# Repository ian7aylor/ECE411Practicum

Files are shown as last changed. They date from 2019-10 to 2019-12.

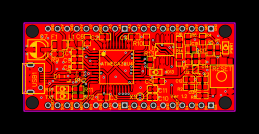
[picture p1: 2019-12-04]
PCB Design & Layout/Layout/Ver1.2/PCB_Micro-Complete-Ver1.2_20191123182726.png

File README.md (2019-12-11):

# ECE411 Practicum: Audio Spectrum Vizualizer, Team #2
## Project Overview
Our device will listen to the surounding environment through a microphone, and 
produce a visual display through an array of colorful LED lights. The LEDs are divided
into seven rows to represent the weight of seven predetermined frequencies. 
The device is powered via USB 2.0 and as a sleek design allow the the device to easily 
be portable. This makes it the perfect product for music listeners, as all they have 
to do is:
1. Power the device with a USB 2.0.
2. Play their favorite soundtrack.
3. Enjoy the visual LED display

## Useful Links
### Link: [Final Version of Board](https://github.com/ian7aylor/ECE411Practicum/tree/master/PCB%20Design%20%26%20Layout/VER1.3)
### Link: [Bill of Materials](https://github.com/ian7aylor/ECE411Practicum/blob/master/BOM/BOM.xlsx)
### Link: [Source Code](https://github.com/ian7aylor/ECE411Practicum/blob/master/Source/ECE_411_Project_Code/ECE_411_Project_Code.ino)
### Link: [Test Plan](https://github.com/ian7aylor/ECE411Practicum/blob/master/Testing/Homework%207%20-%20Test%20Plan.pdf)

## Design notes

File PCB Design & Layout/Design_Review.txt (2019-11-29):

Design Review Notes - Team #2 (Nick Long, Marcus Chalona, Ali Saad, Ian Taylor)
Reviewer: Professor Greenberg 

- Don't know what the schematic is of. Need to better label all parts of the schematic. (fixed)
- Needs to have a "useful" name (fixed)
- 10000 ft view, what does the device do? Should not be a mystery. (fixed)
Solution: Added a title that clearly describes the product. Clearly labeled all major pieces of the schematic.

- Symbols were disliked. In particular the Op-Amp symbol was not liked. (fixed)
Solution: The filter schematic was replaced by an IC. We are no longer building filters from scratch.

Different ground symbols were on the filter circuit. (fixed)
Solution: This is no longer an issue. All ground symbols are the same now.

- LM324 - Put inputs to ground if not used
- Ground VCC on LM324 (fixed)
- Put a decoupling capacitor on the op amp. (fixed)
Solution: We are no longer using the LM324 op-amp.

- Pin Headers need to be labeled. (fixed)
Solution: All pin headers are now labeled.

- Connections to LED Strips/Array (fixed)
Solution: There are now 3 pins for the 8x8 LED array. They connect to the D7 data input, ground, and +5V.

 - 1 Decoupling cap per VCC (fixed)
 Solution: All VCCs now have an assoicated decoupling cap. 
 
 - No stitching ground plane (fixed)
 Solution: Ground planes are now stitched together. There is now one reference across all layers of the board.
 
 - via to connect ground planes (fixed)
 Solution: vias have been added.

 - No reason to use 6 mil wires. (fixed)
 - The wires need to be orthogonal to the pads. (Working on)
Solution: Wire size has been increased to 10 mil, and wires are now orthogonal to pads with proper spacing.

Board has now been finalized and sent out to LCSC for manufacturing.

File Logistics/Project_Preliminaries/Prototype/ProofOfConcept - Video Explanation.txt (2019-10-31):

List of items seen in the video:
1. The 1st shot shows the ADC values being displayed on the serial monitor in the Arduino IDE.
These values are coming from the outputs of the three bandpass filters.
2. The next item seen is the bandpass filter circuit. The LEDs light up when the freuency band goes through/
The closer to the center frequency, the brighter the LED gets.
3. The potentiometers change the feedback resistance to the amplifier that goes to the speaker.
4. The oscilloscope is displaying the signal that would go to the NeoPixel matrix. This particular
signal would say "Howdy!" across the LED matrix.

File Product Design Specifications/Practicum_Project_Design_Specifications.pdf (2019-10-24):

# Practicum

## ViSound Project Design Specifications

V.1

Portland State University

Maseeh College of Engineering & Computer Science

Department of Electrical & Computer Engineering

### Authors:

Nick Long

Marcus Chalona

Ali Saad

Ian Taylor

### October 24, 2019

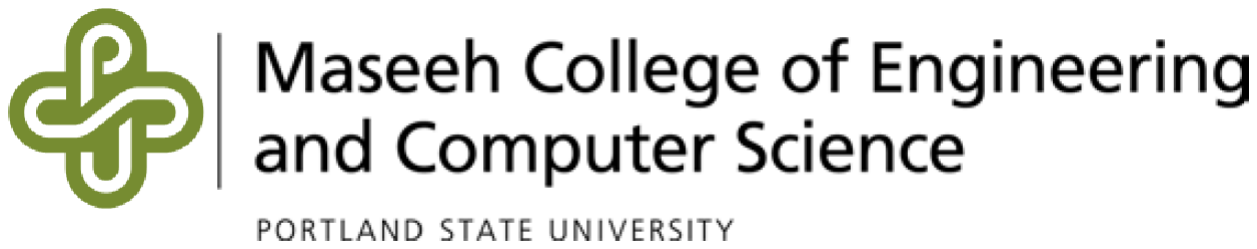
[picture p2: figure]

ECE 411

Industry Design Processes

Lab 1 Report | PSU ECE 411

## Contents

1 Project Summary | 2
2 Market Analysis | 3
3 Requirements | 4
4 System Architecture | 5
5 Design Specification | 6
1900 SW 4th Ave,, Portland, OR 97201 • https://github.com/ECE411Practicum (https://github.com/ian7aylor/ECE411Practicum/) | 1

## 1 Project Summary

ViSound is a device that when powered by a USB 2.0, will listen to the environment through a microphone, and produce a visual display through an array of colorful LED lights. The USB 2.0 feature allows for the device to be portable. This is the perfect product for music listeners, as all they have to do is:

1. Power the device with a USB 2.0.
2. Play their favorite soundtrack.
3. Enjoy the visual LED display.

This product is not only great for music, but also is an item that electronic enthusiasts can tinker with. The USB 2.0 input powers the device, and can be accessed to reprogram the microprocessor. The initial code for this device is provided at https://github.com/ian7aylor/ECE411Practicum and is commented in a user-friendly manner. In order for a user to program the LED display, they should:

1. Plug the device into their computer via USB 2.0.
2. Go to https://github.com/ian7aylor/ECE411Practicum for examples.
3. Reprogram the LED display.
4. Enjoy their unique device.
1900 SW 4th Ave,, Portland, OR 97201 • https://github.com/ECE411Practicum (https://github.com/ian7aylor/ECE411Practicum/) | 2

## 2 Market Analysis

The intended customer base for ViSound are:

- music listeners
- electronic enthusiasts

This is the targeted customer base, but this device can ultimately be used by anyone. There are a few competitors out there that have similar products to ViSound . A couple of these companies are:

- Nobsound
- Nanoleaf

Nobsound has a frequency spectrum analyzer for high fidelity. This is a handheld spectrum analyzer that does a frequency sweep and displays the power for each frequency band with LEDs. The LEDs are monochromatic. This device costs $139. Nanoleaf light panels are smart lights, meaning they can connect to the user’s WiFi. They sell an attachment called a rhythm module that can be attached to their light panels. The user can program the rhythm and color scheme of the LED panels through the Nanoleaf mobile app. When there are environmental sounds, the lights will dance. The minimum cost for this setup is $200.
Companies like Nanoleaf and Nobsound are competitors because their products create an LED visual display in response to environmental sounds. The main difference between ViSound and its competitors, is that the LED visualizations provide information about which frequency band is being displayed, and the user can program the device to create different visual representations for each frequency band. ViSound is also priced at $69.99 which covers the cost of materials, labor, and approximately $40 to put back into the business. This puts this device at close to half the price of our competitors.
1900 SW 4th Ave,, Portland, OR 97201 • https://github.com/ECE411Practicum (https://github.com/ian7aylor/ECE411Practicum/) | 3

## 3 Requirements

Must

- Have a microphone as a sensor (input).
- Have an amplifier stage to boost the input signal.
- Have Neopixel LEDs as actuators (outputs).
- Have a two layer PCB.
- Have 25% or more surface mount components that can be hand or reflow soldered.
- Have a digital or analog processor.
- Be safe
- Have bandpass filters to isolate each frequency band.
- Use USB 2.0 for power and programming.
- Have comments that describe the code in detail.

Should

- Be portable.
- Have a translucent case.
- Be easy to setup.
- Have a wide range of colors.

May

- Be easy for an inexperienced individual to reprogram.
- Be expandable to add or remove pixels.
1900 SW 4th Ave,, Portland, OR 97201 • https://github.com/ECE411Practicum (https://github.com/ian7aylor/ECE411Practicum/) | 4

## 4 System Architecture

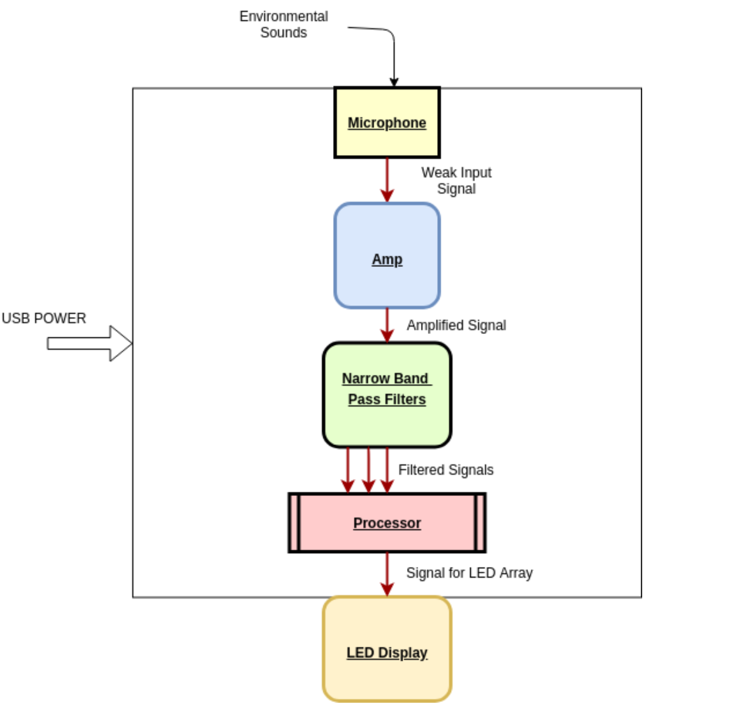
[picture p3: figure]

Figure 1: ViSound - System Architecture

1900 SW 4th Ave,, Portland, OR 97201 • https://github.com/ECE411Practicum (https://github.com/ian7aylor/ECE411Practicum/) | 5

## 5 Design Specification

What is the sensor?

- Microphone (INGHAi GMI6050P-46db)

What is the processor?

- ATMEGA32U4-AU

What is the actuator?

- WS2812 5050 RGB LED with Integrated Drivers

What provides the power?

- USB 2.0 - 5V source(removable male micro-B to male standard type A cable)

What is the mechanical design?

- Translucent Polycarbonate Project Box

What is the firmware?

- Bootloader

What is the programming language?

- AVR C++

Is an Arduino being used? (Y/N)

- Yes

What is the development environment?

- Arduino IDE
1900 SW 4th Ave,, Portland, OR 97201 • https://github.com/ECE411Practicum (https://github.com/ian7aylor/ECE411Practicum/) | 6

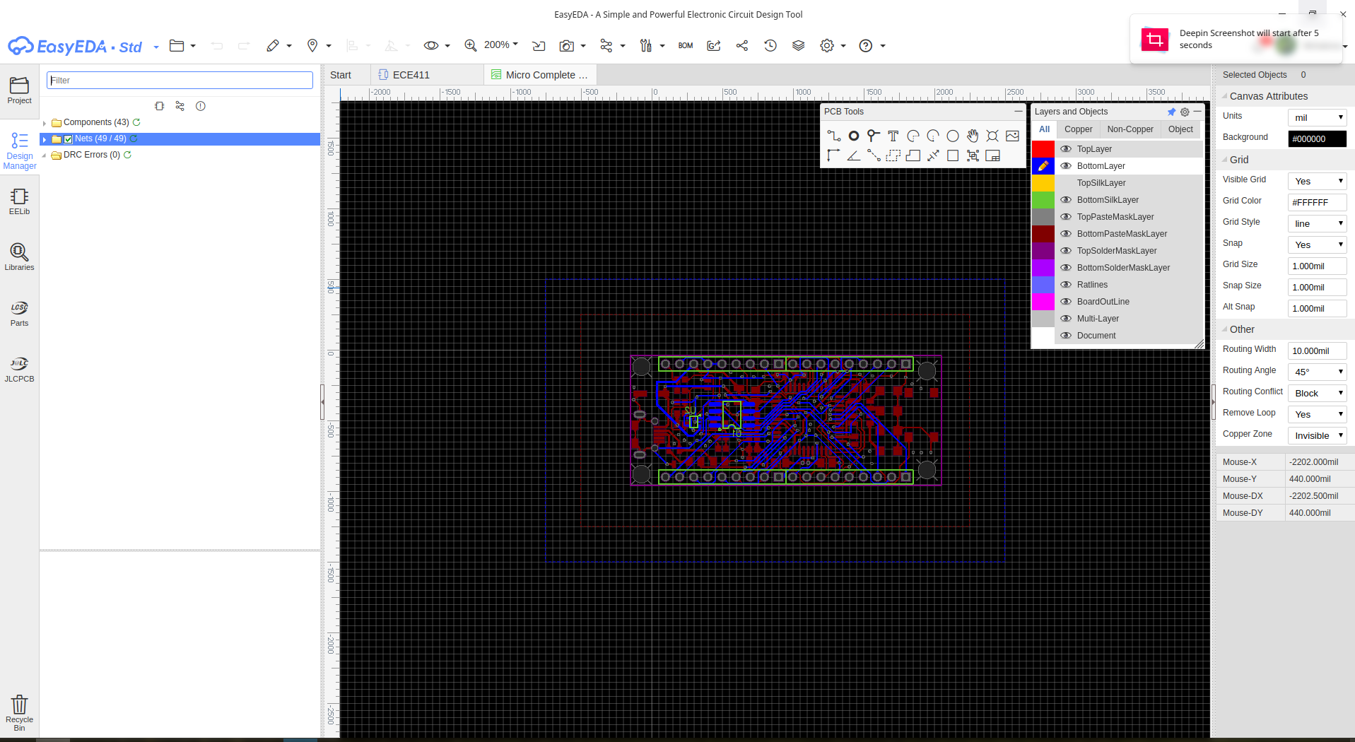
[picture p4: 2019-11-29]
PCB Design & Layout/rulecheck for Ver1.1.png

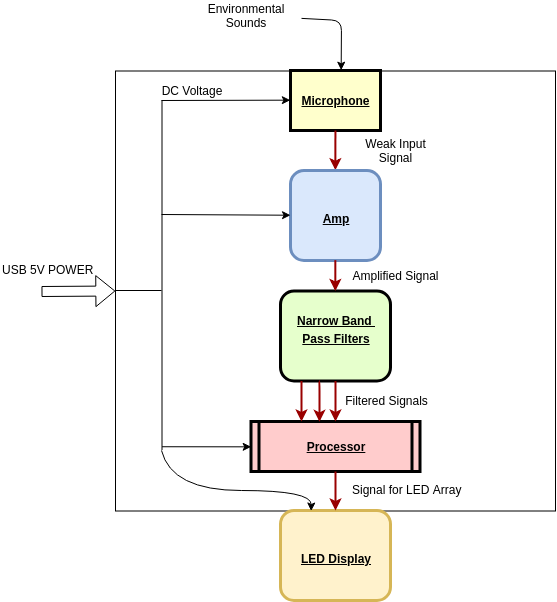
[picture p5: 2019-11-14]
Product Design Specifications/block Diagram.png

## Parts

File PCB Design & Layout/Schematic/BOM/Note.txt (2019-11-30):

BOM needs to be update so that we can use this for board assembly on Monday

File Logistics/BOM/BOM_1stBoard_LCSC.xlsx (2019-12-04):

LCSC Part Number | Manufacture Part Number | Manufacturer | Customer NO. | Package | Description | RoHS | Order Qty. | Min\Mult Order Qty. | Unit Price | Order Price
C10418 | C10418 | Jing Extension of the Electronic Co. |  | SMD | USB Connectors SMD RoHS | Yes | 35 | 5\5 | $0.0576 | $2.02
C106264 | SMD1206P050TF/15 | Polytronics Tech |  | 1206 | PTC Resettable Fuses 1206 RoHS | Yes | 45 | 5\5 | $0.0853 | $3.84
C118556 | 9018H | Semtech |  | TO-92(TO-92-3) | Transistors (NPN/PNP) NPN 50mA 15V TO-92(TO-92-3) RoHS | Yes | 200 | 20\20 | $0.0118 | $2.36
C126020 | LM1117F-5.0 | HTC Korea TAEJIN Tech |  | SOT-89(SOT-89-3) | Low Dropout Regulators(LDO) Positive Fixed 1.3V @ 1A 12V 5V 1A SOT-89(SOT-89-3) RoHS | Yes | 45 | 1\1 | $0.0879 | $3.96
C149873 | CRA064RJ1K00E04Z | Ever Ohms Tech |  | 1206_x4 | Resistor Networks & Arrays 1KOhms ±5% 1/4W 1206_x4 RoHS | Yes | 45 | 5\5 | $0.065 | $2.93
C17513 | 0805W8F1001T5E | Uniroyal Elec |  | 0805 | Chip Resistor - Surface Mount 1KOhms ±1% 1/8W 0805 RoHS | Yes | 700 | 100\100 | $0.0016 | $1.12
C2174 | X206016MSD2SC | Yangxing Tech |  | Radial,2x6mm | Radial Cylinder Crystals 16MHz ±20ppm Radial,2x6mm RoHS | Yes | 20 | 5\5 | $0.0648 | $1.3
C23289 | RVT1V220M0505 | Honor Elec |  | SMD,5x5.4mm | Aluminum Electrolytic Capacitors - SMD 22uF ±20% 35V SMD,5x5.4mm RoHS | Yes | 80 | 20\20 | $0.026 | $2.08
C24658 | 0805CG220J500NT | Guangdong Fenghua Advanced Tech |  | 0805 | Multilayer Ceramic Capacitors MLCC - SMD/SMT 22pF 50V 0805 RoHS | Yes | 300 | 50\50 | $0.0052 | $1.56
C25295 | 0805W8J0220T5E | Uniroyal Elec |  | 0805 | Chip Resistor - Surface Mount 22Ohms ±5% 1/8W 0805 RoHS | Yes | 1200 | 100\100 | $0.0009 | $1.08
C26413 | CL10A105KP8NNNC | Samsung Electro-Mechanics |  | 0603 | Multilayer Ceramic Capacitors MLCC - SMD/SMT 1uF 10V 0603 RoHS | Yes | 100 | 20\20 | $0.0211 | $2.11
C284938 | LTST-C21KGKT | Lite-On |  | SMD,3.2x1.6x1.1mm | Light Emitting Diodes (LED) Green 567.5~576.5nm 28~180mcd Surface Mount SMD,3.2x1.6x1.1mm RoHS | Yes | 45 | 5\5 | $0.0634 | $2.86
C284940 | LTST-C21KSKT | Lite-On |  | SMD,3.2x1.6x1.1mm | Light Emitting Diodes (LED) Yellow 587nm 28~450mcd Surface Mount SMD,3.2x1.6x1.1mm RoHS | Yes | 60 | 5\5 | $0.0468 | $2.81
C284941 | LTST-C21TBKT | Lite-On |  | SMD,3.2x1.6x1.1mm | Light Emitting Diodes (LED) Blue 465~475nm 45~280mcd Surface Mount SMD,3.2x1.6x1.1mm RoHS | Yes | 45 | 5\5 | $0.0634 | $2.86
C294565 | TSA063G50-250 | BRIGHT |  | SMD | Tactile Switches SPST 6.10mm x 6.10mm 1.50mm 50mA @ 12VDC SMD RoHS | Yes | 60 | 20\20 | $0.0207 | $1.25
C305407 | 9012-H | Foshan Blue Rocket Elec |  | TO-92 | Transistors (NPN/PNP) PNP 500mA 20V TO-92 RoHS | Yes | 200 | 20\20 | $0.0121 | $2.42
C356820 | AZ5125-02S.R7G | AMAZING |  | SOT23-3L | TVS SOT23-3L RoHS | Yes | 70 | 10\10 | $0.0347 | $2.43
C50503 | MLB2012-300P3A(f) | Meled Industrial |  | 0805 | Beads 0805 RoHS | Yes | 150 | 50\50 | $0.0087 | $1.31
C50981 | C50981 | Boom Precision Elec |  | 2.54mm | Pin Header & Female Header 2.54mm RoHS | Yes | 70 | 5\5 | $0.0453 | $3.18
C75469 | FDN340P | ON Semicon |  | SOT-23(SOT-23-3) | MOSFET P Trench 20V 2A 1.5V @ 250uA 70 mΩ @ 2A,4.5V SOT-23(SOT-23-3) RoHS | Yes | 70 | 1\1 | $0.0818 | $5.73
C84376 | RC0805FR-0710KL | YAGEO |  | 0805 | Chip Resistor - Surface Mount 10KOhms ±1% 1/8W 0805 RoHS | Yes | 300 | 100\100 | $0.0017 | $0.51
C88136 | 0603B104J500NT | Guangdong Fenghua Advanced Tech |  | 0603 | Multilayer Ceramic Capacitors MLCC - SMD/SMT 100nF 50V 0603 RoHS | Yes | 200 | 50\50 | $0.0091 | $1.82
C95414 | LP2985-33DBVR | Texas Instruments |  | SOT-23-5 | Low Dropout Regulators(LDO) Positive Fixed 575mV @ 150mA 16V 3.3V 150mA SOT-23-5 RoHS | Yes | 50 | 1\1 | $0.2273 | $11.37
Manufacturer Part Number | Manufacturer | Digi-Key Part Number | Customer Reference | Reference Designator | Packaging | Part Status | Quantity | Unit Price | Extended Price | Quantity Available | Mfg Std Lead Time | Description | RoHS Status | Lead Free Status | REACH Status
CMEJ-4618-42-L015 | CUI Devices | 102-6532-ND |  |  | Box | Active | 1 | 0.52 | $0.52 | 3442 | 6 Weeks | MICROPHONE, 4.6 MM, ELECTRET CON | RoHS Compliant | Lead free | Not Available
ATMEGA32U4-AUR | Microchip Technology | ATMEGA32U4-AURCT-ND |  |  | Cut Tape (CT) | Active | 1 | 4.08 | $4.08 | 0 | 6 Weeks | IC MCU 8BIT 32KB FLASH 44TQFP | ROHS3 Compliant | Lead free | REACH Unaffected

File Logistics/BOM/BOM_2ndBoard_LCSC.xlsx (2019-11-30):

LCSC Part Number | Manufacture Part Number | Manufacturer | Package | Customer # | Description | RoHS | Order Qty. | Min\Mult Order Qty. | Unit Price | Order Price | Product Link
C25811 | 0603WAF2003T5E | UNI-ROYAL(Uniroyal Elec) | 603 |  | 200K ±1% 1/10W 0603 Chip Resistor - Surface Mount RoHS | - | 1200 | 100\100 | 0.0006 | 0.72 | https://lcsc.com/product-detail/Chip-Resistor-Surface-Mount_UNI-ROYAL-Uniroyal-Elec-0603WAF2003T5E_C25811.html
C14675 | RC0603FR-07100KL | YAGEO | 603 |  | 100K ±1% 1/10W 0603 Chip Resistor - Surface Mount RoHS | - | 1000 | 100\100 | 0.0007 | 0.7 | https://lcsc.com/product-detail/Chip-Resistor-Surface-Mount_YAGEO-RC0603FR-07100KL_C14675.html
C309445 | AF122-JR-0722RL | YAGEO | 0402x2 |  | 22 ±5% 1/16W 0402x2 Resistor Networks & Arrays RoHS | - | 100 | 50\50 | 0.0145 | 1.45 | https://lcsc.com/product-detail/Resistor-Networks-Arrays_YAGEO-AF122-JR-0722RL_C309445.html
C88136 | 0603B104J500NT | FH(Guangdong Fenghua Advanced Tech) | 603 |  | 100nF 50V 0603 Multilayer Ceramic Capacitors MLCC - SMD/SMT RoHS | - | 100 | 50\50 | 0.0095 | 0.95 | https://lcsc.com/product-detail/Multilayer-Ceramic-Capacitors-MLCC-SMD-SMT_FH-Guangdong-Fenghua-Advanced-Tech-0603B104J500NT_C88136.html
C1635 | 0603CG101J500NT | FH(Guangdong Fenghua Advanced Tech) | 603 |  | 100pF 50V 0603 Multilayer Ceramic Capacitors MLCC - SMD/SMT RoHS | - | 400 | 100\100 | 0.0028 | 1.12 | https://lcsc.com/product-detail/Multilayer-Ceramic-Capacitors-MLCC-SMD-SMT_FH-Guangdong-Fenghua-Advanced-Tech-0603CG101J500NT_C1635.html
C305012 | RTT031002BTP | RALEC | 603 |  | 10K ±0.1% 1/10W 0603 Chip Resistor - Surface Mount RoHS | - | 60 | 20\20 | 0.0227 | 1.362 | https://lcsc.com/product-detail/Chip-Resistor-Surface-Mount_RALEC-RTT031002BTP_C305012.html
C124567 | 0603B103J500NT | FH(Guangdong Fenghua Advanced Tech) | 603 |  | 10nF 50V 0603 Multilayer Ceramic Capacitors MLCC - SMD/SMT RoHS | - | 200 | 50\50 | 0.0053 | 1.06 | https://lcsc.com/product-detail/Multilayer-Ceramic-Capacitors-MLCC-SMD-SMT_FH-Guangdong-Fenghua-Advanced-Tech-0603B103J500NT_C124567.html
C115325 | RS-03K1001FT | FH(Guangdong Fenghua Advanced Tech) | 603 |  | 1K ±1% 1/10W 0603 Chip Resistor - Surface Mount RoHS | - | 1600 | 100\100 | 0.0006 | 0.96 | https://lcsc.com/product-detail/Chip-Resistor-Surface-Mount_FH-Guangdong-Fenghua-Advanced-Tech-RS-03K1001FT_C115325.html
C388038 | 0603N220F500CT | Walsin Tech Corp | 603 |  | 22pF 50V 0603 Multilayer Ceramic Capacitors MLCC - SMD/SMT RoHS | - | 100 | 50\50 | 0.0088 | 0.88 | https://lcsc.com/product-detail/Multilayer-Ceramic-Capacitors-MLCC-SMD-SMT_Walsin-Tech-Corp-0603N220F500CT_C388038.html
C105578 | RC0603FR-071ML | YAGEO | 603 |  | 1M ±1% 1/10W 0603 Chip Resistor - Surface Mount RoHS | - | 1600 | 100\100 | 0.0007 | 1.12 | https://lcsc.com/product-detail/Chip-Resistor-Surface-Mount_YAGEO-RC0603FR-071ML_C105578.html
C105576 | RC0603FR-072KL | YAGEO | 603 |  | 2K ±1% 1/10W 0603 Chip Resistor - Surface Mount RoHS | - | 1600 | 100\100 | 0.0007 | 1.12 | https://lcsc.com/product-detail/Chip-Resistor-Surface-Mount_YAGEO-RC0603FR-072KL_C105576.html
C296062 | 0603N330F500CT | Walsin Tech Corp | 603 |  | 33pF 50V 0603 Multilayer Ceramic Capacitors MLCC - SMD/SMT RoHS | - | 200 | 50\50 | 0.0117 | 2.34 | https://lcsc.com/product-detail/Multilayer-Ceramic-Capacitors-MLCC-SMD-SMT_Walsin-Tech-Corp-0603N330F500CT_C296062.html

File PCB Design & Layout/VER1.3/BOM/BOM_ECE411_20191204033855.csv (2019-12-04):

ID | Name | Designator | Footprint | Quantity | Manufacturer Part | Manufacturer | Supplier | Supplier Part | LCSC Assembly
1 | AZ5125-02S.R7G | D1 | SOT-23-3_L2.9-W1.6-P1.90-LS2.8-BR | 1 | AZ5125-02S.R7G | AMAZING | LCSC | C356820
2 | 100K | R3 | 0603' | 1 | RC0603FR-07100KL | YAGEO | LCSC | C14675
3 | ATMEGA32U4-AU | ATMEGA32U4 | QFP-44_10X10X08P | 1 | ATMEGA32U4-AU | MICROCHIP | LCSC | C44854 | Yes
4 | LTST-C21TBKT | PWR1 | LED-SMD-3.2X1.6X1.1 | 1 | LTST-C21TBKT | Lite-On | LCSC | C284941
5 | 22 | RN2 | RES-ARRAY-SMD_0402-4P-L1.0-W1.0-BL | 1 | AF122-JR-0722RL | YAGEO | LCSC | C309445
6 | LTST-C21KGKT | IO13 | LED-SMD-3.2X1.6X1.1 | 1 | LTST-C21KGKT | Lite-On | LCSC | C284938
7 | LTST-C21KSKT | RX1,TX1 | LED-SMD-3.2X1.6X1.1 | 2 | LTST-C21KSKT | Lite-On | LCSC | C284940
8 | A2541WV-9P | H2,H3,H1,H4 | SIP-2.54MM-9P-CJT-H8.54 | 4 | A2541WV-9P | Changjiang Connectors | LCSC | C225484
9 | 30Ω | L1 | 0805' | 1 | MLB2012-300P3A(f) | ReliaPro | LCSC | C50503
10 | 100nF | C2,C14,C3,C4,C8,C1,C5 | 0603' | 7 | 0603B104J500NT | FH | LCSC | C88136
11 | 100pF | C13 | 0603' | 1 | 0603CG101J500NT | FH | LCSC | C1635 | Yes
12 | 10K | R2,R8,R9 | 0603' | 3 | RTT031002BTP | RALEC | LCSC | C305012
13 | micro USBFemale | USB1 | MICRO-USB-1 | 1 | micro USBFemale | ValuePro | LCSC | C10418
14 | MAX4466EXK+T | U2 | SC-70-5 | 1 | MAX4073TAXK+T | Maxim Integrated | LCSC | C143459 | Yes
15 | 10nF | C15,C17 | 0603' | 2 | 0603B103J500NT | FH | LCSC | C124567
16 | 16MHz | X1 | TXAL-1.9*6 | 1 | X206016MSD2SC | YXC | LCSC | C2174
17 | 1uF | C9,C12,C6 | 0603' | 3 | CL10A105KP8NNNC | SAMSUNG | LCSC | C26413
18 | 1K | R1,R13,R12,R11,R10 | 0603' | 5 | RS-03K1001FT | FH | LCSC | C115325
19 | TSA063G50-250 | RESET | SW-SMD-T6X6-9.5X5.8 | 1 | TSA063G50-250 | BRIGHT | LCSC | C294565
20 | MSGEQ7SOIC | U1 | SOIC-8 | 1
21 | 22uF | C7 | CAP-SMD_BD5.0-L5.3-W5.3-FD | 1 | RVT1V220M0505 | HONOR | LCSC | C23289
22 | 200K | R14 | R0603 | 1 | CR0603F200KP05 | Ever Ohms Tech | LCSC | C429255
23 | 22pF | C10,C11 | CAP_0603 | 2 | 0603N220F500CT | Walsin Tech Corp | LCSC | C388038
24 | 1M | R6,R7 | 0603' | 2 | RC0603FR-071ML | YAGEO | LCSC | C105578
25 | 2K | R4,R5 | 0603' | 2 | RC0603FR-072KL | YAGEO | LCSC | C105576
26 | SMD1206P050TF/15 | F1 | FUSE-1206 | 1 | SMD1206P050TF/15 | PTTC | LCSC | C106264
27 | 33pF | C16 | 0603' | 1 | 0603N330F500CT | Walsin Tech Corp | LCSC | C296062

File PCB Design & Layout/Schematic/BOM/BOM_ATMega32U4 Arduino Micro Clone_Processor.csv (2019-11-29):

ID | Name | Designator | Footprint | Quantity | Manufacturer Part | Manufacturer | Supplier | Supplier Part | LCSC Assembly
1 | none | A |  | 1
2 | AZ5125-02S.R7G | D1 | SOT-23-3_L2.9-W1.6-P1.90-LS2.8-BR | 1 | AZ5125-02S.R7G | AMAZING | LCSC | C356820
3 | ATMEGA32U4-AU | ATMEGA1U4-AU | QFP-44_10X10X08P | 1 | ATMEGA32U4-AU | MICROCHIP | LCSC | C44854 | Yes
4 | LTST-C21TBKT | PWR1 | LED-SMD-3.2X1.6X1.1 | 1 | LTST-C21TBKT | Lite-On | LCSC | C284941
5 | LTST-C21KGKT | IO1 | LED-SMD-3.2X1.6X1.1 | 1 | LTST-C21KGKT | Lite-On | LCSC | C284938
6 | 1K | RN1 | 1206_X4 | 1 | CRA064RJ1KE04 | EVER OHMS | LCSC | C149873
7 | 1K | R2 | 0805' | 1 | 0805W8F1001T5E | UniOhm | LCSC | C17513 | Yes
8 | LTST-C21KSKT | TX1,RX1 | LED-SMD-3.2X1.6X1.1 | 2 | LTST-C21KSKT | Lite-On | LCSC | C284940
9 | A2541WV-9P | H3,H1,H2,H4 | SIP-2.54MM-9P-CJT-H8.54 | 4 | A2541WV-9P | Changjiang Connectors | LCSC | C225484
10 | 22pF | C11,C10 | 0805' | 2 | 0805CG220J500NT | FH | LCSC | C24658
11 | 30Ω | L1 | 0805' | 1 | MLB2012-300P3A(f) | ReliaPro | LCSC | C50503
12 | LP2985-33DBVR | U2 | SOT-23-5 | 1 | LP2985-33DBVR | TI | LCSC | C95414 | Yes
13 | 100nF | C4,C1,C5,C8 | 0603' | 4 | 0603B104J500NT | FH | LCSC | C88136
14 | micro USBFemale | USB1 | MICRO-USB-1 | 1 | micro USBFemale | ValuePro | LCSC | C10418
15 | 16MHz | X1 | TXAL-1.9*6 | 1 | X206016MSD2SC | YXC | LCSC | C2174
16 | FDN340P | Q2,Q1 | SOT-23-3_L2.9-W1.6-P1.90-LS2.8-BR | 2 | FDN340P | FAIRCHILD | LCSC | C75469 | Yes
17 | 1uF | C3,C9,C6 | 0603' | 3 | CL10A105KP8NNNC | SAMSUNG | LCSC | C26413
18 | TSA063G50-250 | RESET | SW-SMD-T6X6-9.5X5.8 | 1 | TSA063G50-250 | BRIGHT | LCSC | C294565
19 | 22 | R4,R3 | 0805' | 2 | 0805W8J0220T5E | UniOhm | LCSC | C25295
20 | 22uF | C7,C2 | CAP-SMD_BD5.0-L5.3-W5.3-FD | 2 | RVT1V220M0505 | HONOR | LCSC | C23289
21 | LM1117F-5.0 | U1 | SOT-89(SOT-89-3) | 1 | LM1117F-5.0 | HTC | LCSC | C126020 | Yes
22 | 10K | R1,R5 | 0805' | 2 | RC0805FR-0710KL | YAGEO | LCSC | C84376
23 | SMD1206P050TF/15 | F1 | FUSE-1206 | 1 | SMD1206P050TF/15 | PTTC | LCSC | C106264

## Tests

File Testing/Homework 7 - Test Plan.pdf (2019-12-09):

Homework 7 - Audio Spectrum Visualizer: System Test Plan Authors: Nicholas Long, Marcus Chalona, Ian Taylor, Ali Saad EC411- Team #2
12/3/2019 - Revision 1.0

Table of Contents

1. Introduction | 2
2. Reference Documents | 3
3. Test Objectives | 4
4. System Tests | 5
4.1 Unit Tests
4.1.1 Microphone
4.1.2 Preamplifier
4.1.3 7 Band Bandpass Filter 4.1.4 Atmel ATmega32U4
a. Matrix Array Signal
4.1.5 LED Matrix Array
4.2 Integration Tests
4.2.1 1st Stage (Microphone + Preamp)
4.2.2 2nd Stage (Atmel ATmega32U4 + 7 Band Bandpass Filter)
4.2.3 3rd Stage (Atmel ATmega32U4 + LED Matrix)
a. Signal to LED Matrix
4.2.4 1st + 2nd Stage (Atmel ATmega32U4 + 7 Band Bandpass Filter + Preamp) 4.3 Acceptance Tests
4.3.1 Frequency Sweep Mapping to LED Matrix
5. Resources
5.1 Tektronix MSO 4054 Mixed Signal Oscilloscope 5.2 Arbitrary Waveform Generator
5.3 Computer
5.3.1 Software: Atmel Studio, Arduino IDE. 5.3.2 Programing Language: Processing 5.4 Testing Cables/Probes
5.4.1 Female - Male BNC Cable
5.4.2 Oscilloscope Probes
5.5 8 Ohm Speaker
5.6 Personnel
5.6.1 Education: Electrical/Computer Engineering Student/Graduate
5.6.2 Skills required: Ability to navigate equipment such as an oscilloscope, arbitrary waveform generator, DC power supply and have C programming knowledge.

Introduction

The Audio Spectrum Visualizer is a device that takes in audio input and displays the frequency bands with their related signal strength on an LED matrix. Each frequency band is associated with a certain color. Below is a block diagram that illustrates the Audio Spectrum Visualizer on an abstract level.

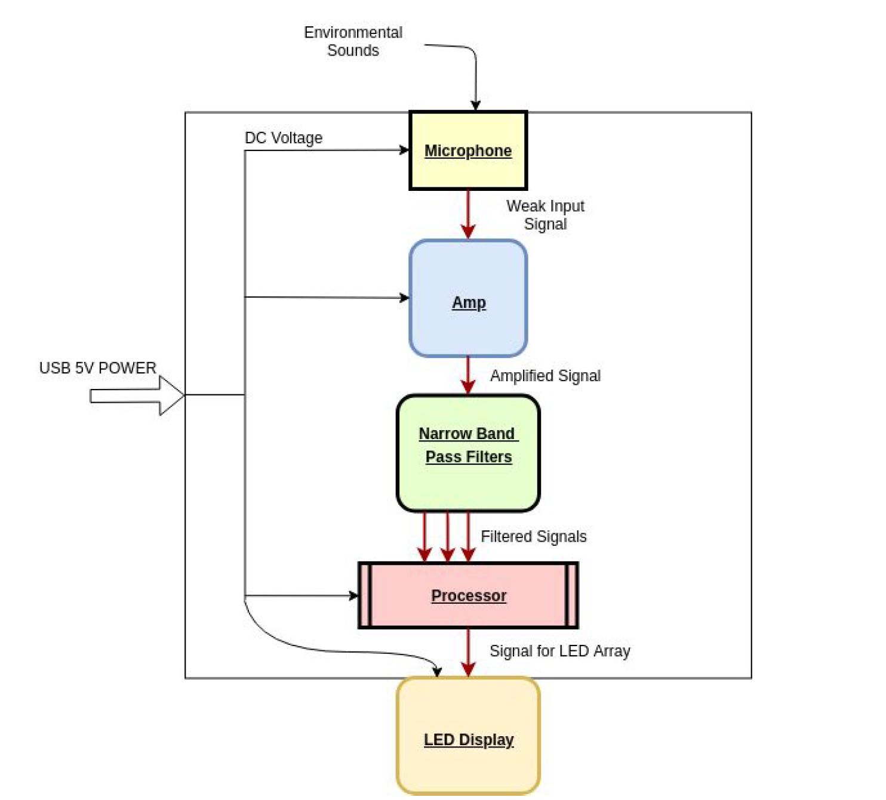
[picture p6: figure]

Reference Documentation

Below are links to all of the documents needed to thoroughly test the Audio Spectrum Visualizer.

Product Design Specifications (PDS)
Product Design Specifications (https://github.com/ian7aylor/ECE411Practicum/blob/master/Product_Design_Specifications/Practicum_Project_Design_Specifications.pdf)

Board Schematic & Layout
Ver1.3 Schematic (https://github.com/ian7aylor/ECE411Practicum/blob/master/PCB%20Design%20%26%20Layout/VER1.3/Schematic/Schematic_ECE411_ATMEGA32U4%20Micro%20Ver1.3_20191204033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)
Ver1.3 Layout (https://github.com/ian7aylor/ECE411Practicum/blob/master/PCB%20Design%20%26%20Layout/VER1.3/PCB%20Layout/PCB_Micro%20Complete%20Ver1.3_20191204033932.pdf)

Datasheets
Microphone Preamplifier (https://github.com/ian7aylor/ECE411Practicum/blob/master/Datasheets/MAX4465-MAX4469.pdf)
MSGEQ7 - Seven Band Graphic Equalizer (https://github.com/ian7aylor/ECE411Practicum/blob/master/Datasheets/MSGEQ7.pdf) SK6812 - Programmable LED (https://github.com/ian7aylor/ECE411Practicum/blob/master/Datasheets/SK6812%2BLED%2Bdatasheet%2B.pdf)
Atmel ATmega32U4 - 8-bit microcontroller (https://github.com/ian7aylor/ECE411Practicum/blob/master/Datasheets/atmel-7766-8-bit-avr-atmega16u4-32u4_datasheet.pdf) WS2812B - Intelligent Control LED (https://github.com/ian7aylor/ECE411Practicum/blob/master/Datasheets/WS2812B.pdf)

Test Objectives

Unit Testing:
Testing each individual module using the module’s specification as a description of desired behavior helps to ensure that each individual system is working correctly prior to integration. The systems that need to work according to their datasheet prior to integration are:
- MSGEQ7 7 band bandpass filter
- Microphone
- Microphone Preamplifier
- Atmel Atmega32U4 8-bit microcontroller
Once these units have been thoroughly tested and meet the specifications of their respective datasheets, we can confidently move onto integration testing.

Integration Testing:
The purpose of integration testing is to ensure that the modules interact correctly when connected to one another. Each interface needs to be exercised prior to the entire system being put together. Once integration testing has been thoroughly completed, we can confidently assemble the Audio Spectrum Visualizer and move into acceptance testing.

Acceptance Testing:
The purpose for acceptance testing in our project is to make sure our product design specifications (PDS) are met. This involves both functional and performance testing. Once these tests pass, the project is finalized.

System Tests

Acceptance Test Example:
Test Writers: Nicholas Long, Marcus Chalona, Ian Taylor, Ali Saad
Test Case Name: | Frequency to LED Mapping | Test ID #: | ACC-01
Description: | Verify each frequency is displayed on the correct row of an 8x8 LED matrix with their associated color. | Type: | Black Box Testing

Tester Information

| Name of Tester: | Computer Engineering / Electrical Engineering Student/ Graduate | Date:
Hardware Version: | | 1.3 | Time:
Equipment Needed: | | Audio Spectrum Visualizer (device being tested), Arbitrary Waveform Generator, BNC Speaker
Setup: | | Power on the Audio Spectrum Visualizer. Make sure the system is reset and all LEDs have no input. Set the arbitrary waveform generator to a frequency sweep from 50 Hz - 16 kHz. Using a BNC Female - Male cable, connect the arbitrary waveform generator to a speaker. Make sure the volume is up on the speaker and within 1 foot of the Audio Spectrum Visualizer. Start the frequency sweep on the waveform generator.

Step: | Action: Audio Input Frequency | Expected Result | Pass | Fail | N/A | Comments
1 | Minimum 63 Hz -Maximum 159 Hz | Column 1: LED should light up red with related power level.
2 | Minimum 160 Hz -Maximum 399 Hz | Column 2: LED should light up green with related power level.
3 | Minimum 400 Hz -Maximum 999 Hz | Column 3: LED should light up blue with related power level.
4 | Minimum 1.0 kHz -Maximum 2.4 kHz | Column 4: LED should light up yellow with related power level.
5 | Minimum 2.5 kHz -Maximum 6.2 kHz | Column 5: LED should light up purple with related power level.
6 | Minimum 6.25 kHz -Maximum 15.9 kHz | Column 6: LED should light up white with related power level.

7 | 16.0 kHz | Column 7: LED should light up Aqua with related power level.

Overall Test Result:

Unit Test Example:
Test Writers: Nicholas Long, Marcus Chalona, Ian Taylor, Ali Saad
Test Case Name: | Matrix Array Signal | Test ID #: | ATM-01
Description: | Custom communication protocol for WS2812b LED Array is in the correct frequency range to control LEDs. Frequency must be greater than 400 Hz as per the WS2812B data sheet. This is a white box test as we know the program that is uploaded on the microprocessor. | Type: | White Box Testing

Tester Information

| Name of Tester: | Level I Technician, Electrical Engineering Senior Student/Graduate | Date:
Hardware Version: | | 1.3 | Time:
Equipment Needed: | | Atmel ATmega32U4, Oscilloscope, BNC Female - Male Cable, Computer w/ Arduino software installed, Micro USB cable
Setup: | | Attach USB Power and wait 5 seconds for bootloader to initialize. Hook up BNC Female - Male cable from the oscilloscope to the output pin PE6 of the ATmega32U4. This pin can be seen on the Ver1.3 Schematic.
Step: | Action | Expected Output | Pass | Fail | N/A | Comments
1 | Upload Neopixel LED Matrix “HOWDY” example program from the Adafruit Neopixel library | Frequencies read on oscilloscope are greater than 400 Hz and less than 800 Hz.

Overall Test Result:

Integration Test:
Test Writers: Nicholas Long, Marcus Chalona, Ian Taylor, Ali Saad
Test Case Name: | Signal to LED Matrix | Test ID #: | STG3-01
Description: | LED Matrix Array responds to the signal that was developed in the unit test ATM-01 above. | Type: | White Box Testing

Tester Information

| Name of Tester: | Level I Technician, Electrical Engineering Senior Student/Graduate | Date:
Hardware Version: | | 1.3 | Time:
Equipment Needed: | | Atmel ATmega32U4, 8x8 LED Neopixel Matrix Array, Computer with Arduino software installed, Micro USB cable
Setup: | | Attach USB Power and wait 5 seconds for bootloader to initialize. Make sure the LED Matrix Array is attached to pin PE6 of the ATmega32U4. This pin can be seen on the Ver1.3 Schematic.
Step: | Action | Expected Output | Pass | Fail | N/A | Comments
1 | Upload Neopixel LED Matrix “HOWDY” example program from the Adafruit Neopixel library | “HOWDY” displays on 8x8 LED Neopixel Matrix Array

Overall Test Result:

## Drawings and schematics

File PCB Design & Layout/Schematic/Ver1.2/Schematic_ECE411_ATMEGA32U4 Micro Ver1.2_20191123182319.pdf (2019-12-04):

## Micro USB

## Analog Reference

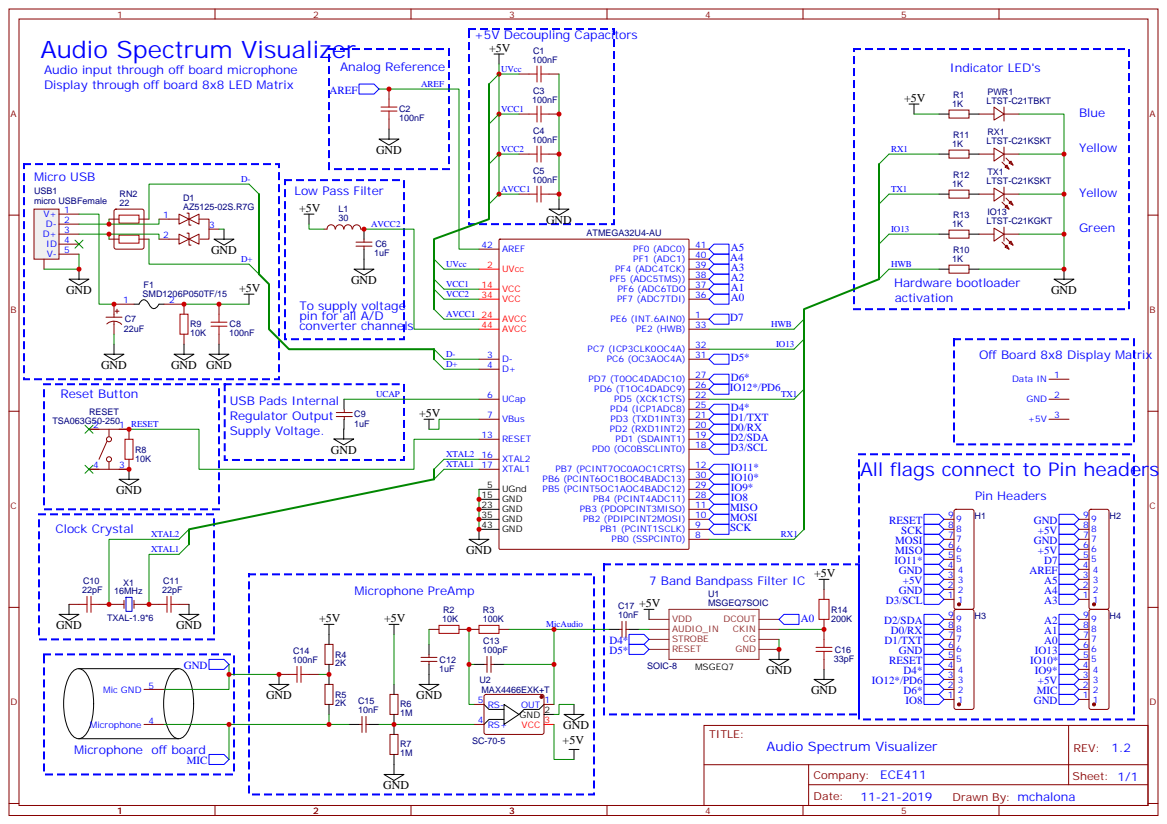
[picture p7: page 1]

Audio input through off board microphone
Display through off board 8x8 LED Matrix

Off Board 8x8 Display Matrix

All flags connect to Pin headers

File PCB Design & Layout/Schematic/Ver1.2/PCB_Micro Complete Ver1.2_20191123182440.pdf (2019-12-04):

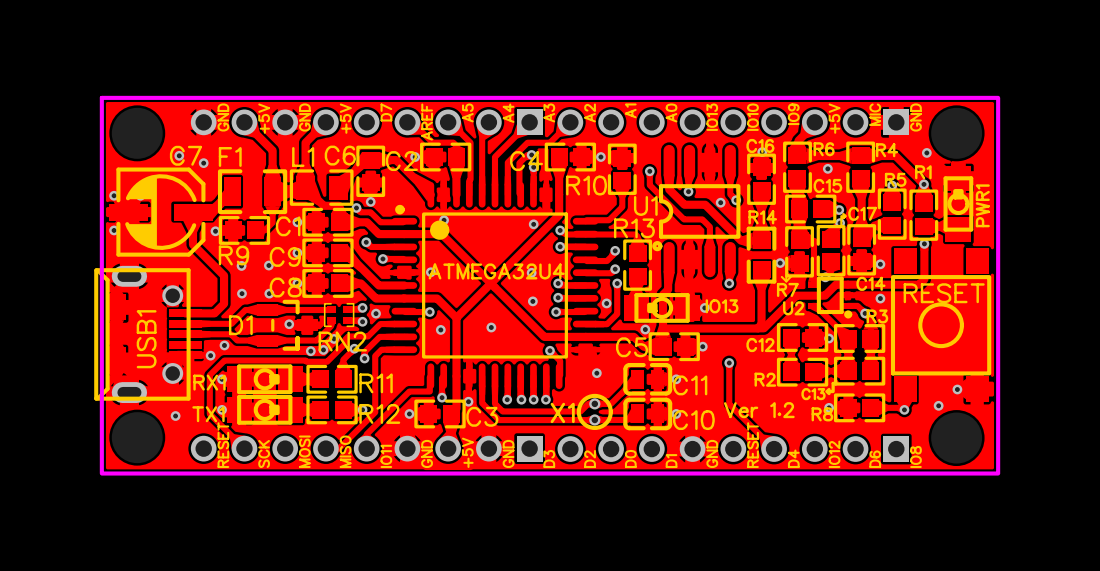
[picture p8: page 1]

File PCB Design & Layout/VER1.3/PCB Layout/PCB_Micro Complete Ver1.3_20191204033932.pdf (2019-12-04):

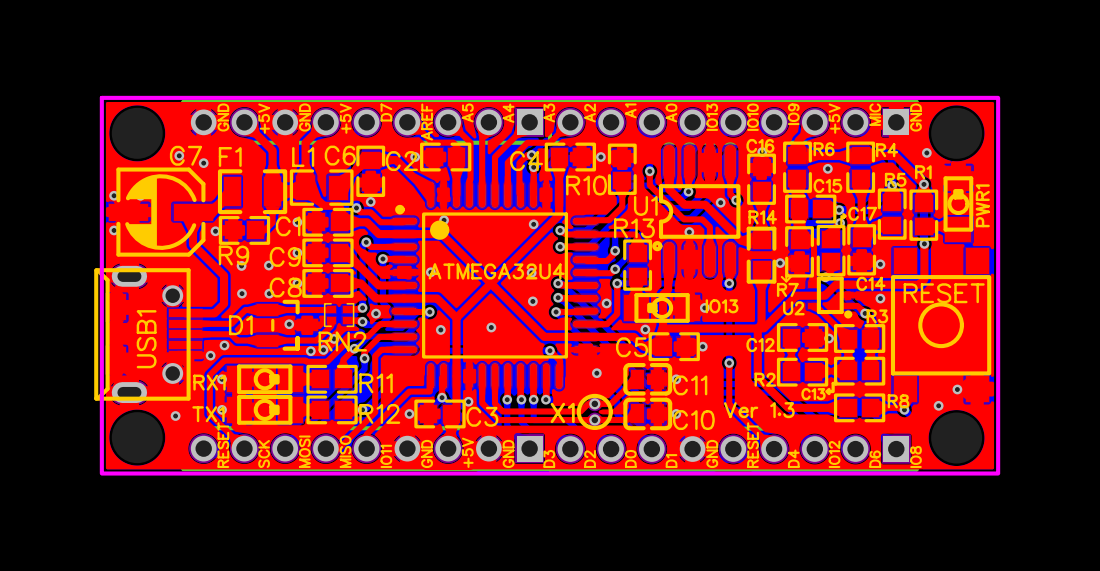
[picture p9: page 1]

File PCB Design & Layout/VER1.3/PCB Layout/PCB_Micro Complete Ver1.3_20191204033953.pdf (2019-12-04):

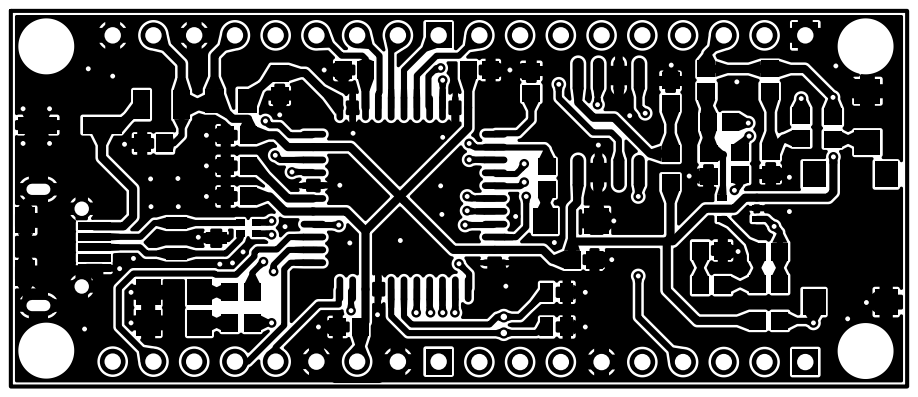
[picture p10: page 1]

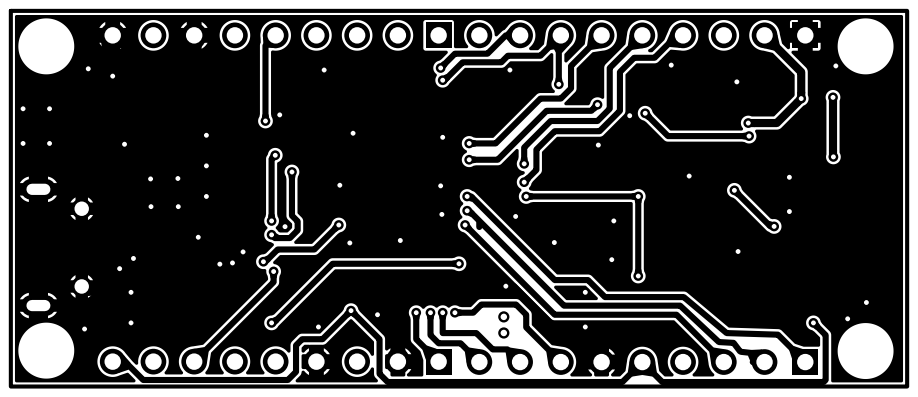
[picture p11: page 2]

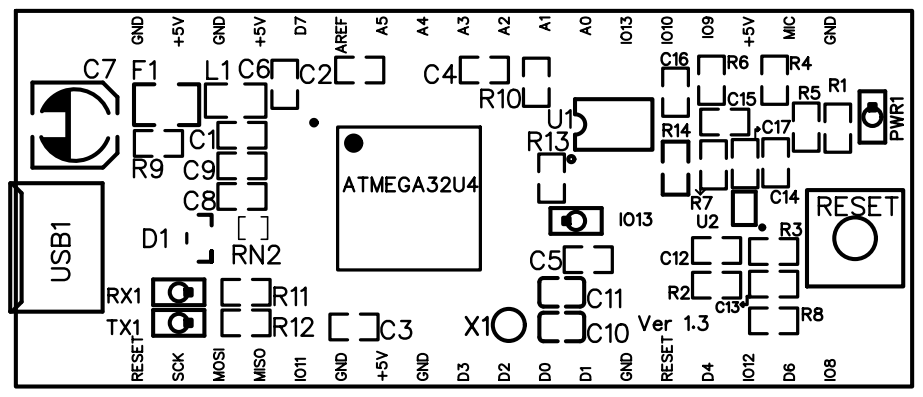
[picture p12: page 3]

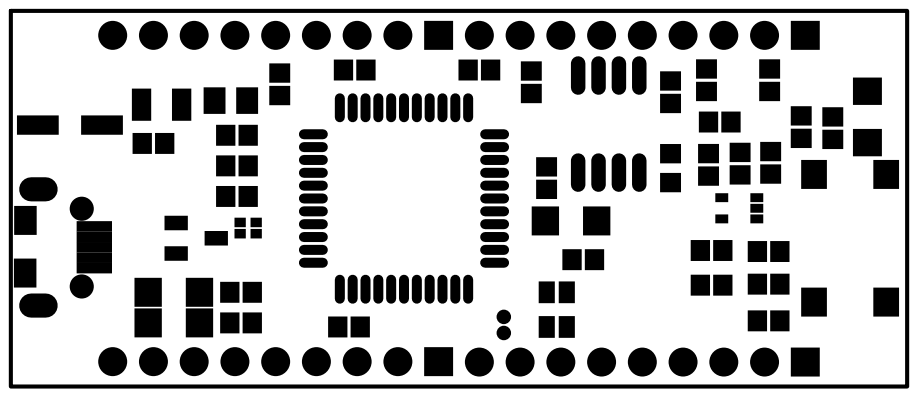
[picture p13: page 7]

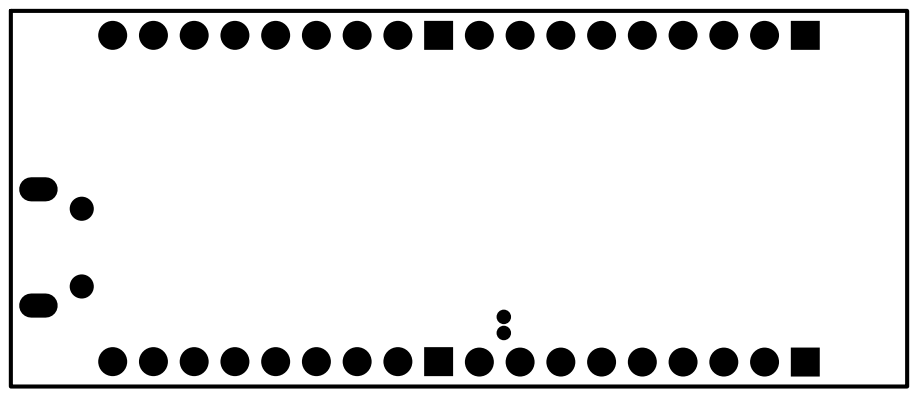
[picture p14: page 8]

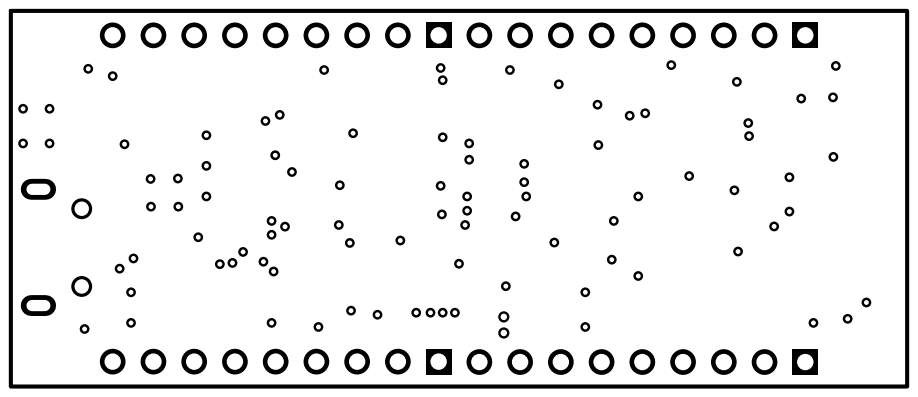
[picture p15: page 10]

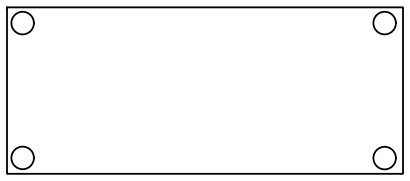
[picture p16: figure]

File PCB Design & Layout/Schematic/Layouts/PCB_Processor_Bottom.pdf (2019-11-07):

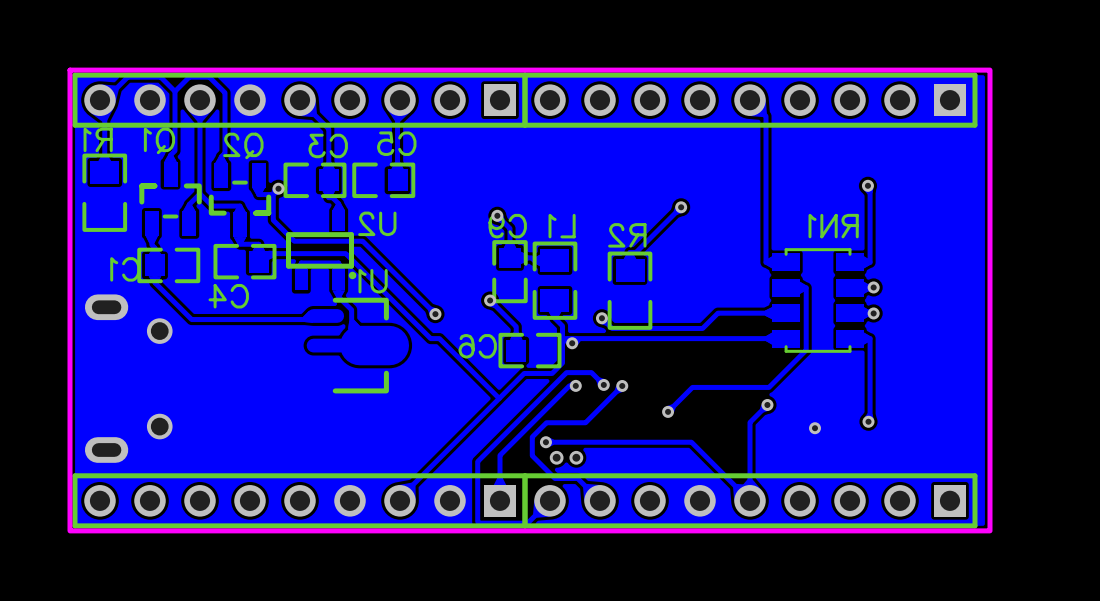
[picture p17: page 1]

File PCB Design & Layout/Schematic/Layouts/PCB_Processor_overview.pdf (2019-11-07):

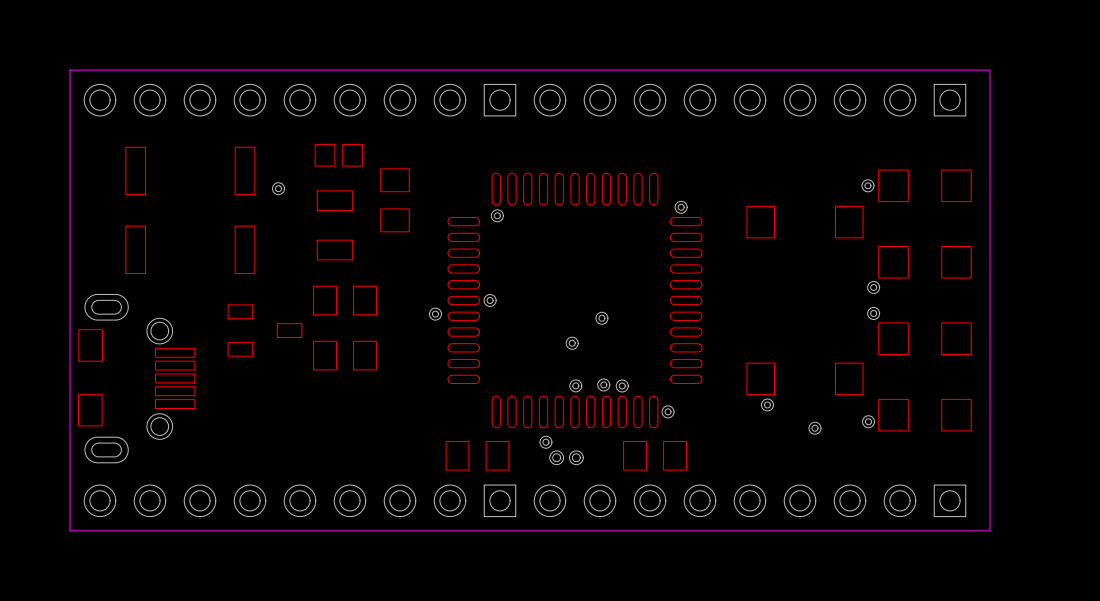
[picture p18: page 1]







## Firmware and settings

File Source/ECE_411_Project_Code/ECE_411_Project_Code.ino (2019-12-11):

// Audio Spectrum Equalizer
// By Ali Saad, Marc Merlin, Nick Long 
// ECE 411 Project Code


///////////////////////////////////////////////////////////////////////////////////////////////

////////////////////////////////// Included Libraries /////////////////////////////////////////

//////////////////////////////////////////////////////////////////////////////////////////////


//Include Library 
#include <FastLED.h>      // Downloaded Library through Arduino IDE application


///////////////////////////////////////////////////////////////////////////////////////////////

////////////////////////////////// Defining Variables ////////////////////////////////////////

//////////////////////////////////////////////////////////////////////////////////////////////

// Array Assignments 
#define DisplayPin 6      // Output data pin for 8x8 NeoPixel Matrix display 
#define LEDBrightness 63  // Controls Brightness of LED, LEDs set to 1/4th the brightness 
#define NumLEDS 64        // Number of LEDs 8 x 8 = 64
CRGB leds[NumLEDS];       // Sets Arrays of LEDs


//  Analog Input
// Color Assignments for LEDs
#define C0 Black          // no input
#define C1 Red            // 1st column of LEDs
#define C2 Green          // 2nd column of LEDs
#define C3 Blue           // 3rd column of LEDs
#define C4 Yellow         // 4th column of LEDs
#define C5 Purple         // 5th column of LEDs
#define C6 White          // 6th column of LEDs
#define C7 Aqua           // 7th column of LEDs
#define C8 Orange         // 8th column of LEDs

///////////////////////////////////////////////////////////////////////////////////////////////

////////////////////////////////// Intialize Variables ////////////////////////////////////////

///////////////////////////////////////////////////////////////////////////////////////////////

int sensorPin = A0;       // select the input pin for the PotValueentiometer
int resetPin = 3;         // digital pin to reset the mux on the equlizer chip
int strobePin = 4;        // strobe pin to sequence through the mux on the equlizer chip
int MaxS = 0;             // variable to store the value coming from the sensor
int Channel_1 = 0;        // 63 Hz Channel Values,   1st Bandpass Channel
int Channel_2 = 0;        // 160Hz Channel Values,   2nd Bandpass Channel
int Channel_3 = 0;        // 400Hz Channel Values,   3rd Bandpass Channel 
int Channel_4 = 0;        // 1khz Channel Values,    4th Bandpass Channel 
int Channel_5 = 0;        // 2.5khz Channel Values,  5th Bandpass Channel 
int Channel_6 = 0;        // 6.25khz Channel Values, 6th Bandpass Channel 
int Channel_7 = 0;        // 16kHz Channel Values,   7th Bandpass Channel 

// Multiplier for each channel 
// The value we read from ADC will be pretty low so the multiplier will give us 
// a bigger range for the low value, to give an adjustable way for matching that range
int ch1 = 2;              // Channel 1 multiplier
int ch2 = 2;              // Channel 2 multiplier
int ch3 = 2;              // Channel 3 multiplier
int ch4 = 2;              // Channel 4 multiplier
int ch5 = 2;              // Channel 5 multiplier
int ch6 = 2;              // Channel 6 multiplier
int ch7 = 2;              // Channel 7 multiplier


//////////////////////////////////////////////////////////////////////////////////////////////

////////////////////////////////// Setup /////////////////////////////////////////////////////

//////////////////////////////////////////////////////////////////////////////////////////////

void setup() {
// Brought in from the FastLED Library
// Block of memory that will be used for storing and manipulating the led data
// This sets up an array that we can manipulate to set/clear led data. 
// Keepin it simple, a way of addressing the LEDs
  FastLED.addLeds<NEOPIXEL, DisplayPin>(leds, NumLEDS);
 
// Declare the strobePin and resetPin as an OUTPUT:
  pinMode(strobePin, OUTPUT);                         // Seting output for Strobe Pin on Bandpass Filter
  pinMode(resetPin, OUTPUT);                          // Seting output for Reset Pin on Bandpasss Filter 

// Used for diagonositics, let's us see output  
  Serial.begin(115200);                               // Serial Monitor and Baud Rate 
  reset();                                            // Reset the equlizer chip for mux operation
  digitalWrite(strobePin, HIGH);                      // Set the strobe pin high to initial state, Strobe = 1 
  
// Sets the LED brightness
// Defined in defining variable section
// Now implementing and setting brightness here
  FastLED.setBrightness(LEDBrightness);

}


//////////////////////////////////////////////////////////////////////////////////////////////

////////////////////////////////// Toogle Pin Output /////////////////////////////////////////

//////////////////////////////////////////////////////////////////////////////////////////////

// Toggle Strobe pin to output the next value from the MUX in the Equalizer Chip
// This dictates which channel to use
void loop() {
  Channel_1 = TogglePinOutput(strobePin, 80)*ch1;   // 63Hz sample  
  DisplayLED(1, Channel_1);                         // Light first column corresponding to input of channel 1
  Channel_2 = TogglePinOutput(strobePin, 80)*ch2;   // 160Hz sample
  DisplayLED(2, Channel_2);                         // Light second column corresponding to input of channel 2
  Channel_3 = TogglePinOutput(strobePin, 80)*ch3;   // 400Hz sample
  DisplayLED(3, Channel_3);                         // Light third column corresponding to input of channel 3
  Channel_4 = TogglePinOutput(strobePin, 80)*ch4;   // 1khz sample
  DisplayLED(4, Channel_4);                         // Light forth column corresponding to input of channel 4
  Channel_5 = TogglePinOutput(strobePin, 80)*ch5;   // 2.5khz sample
  DisplayLED(5, Channel_5);                         // Light fifth column corresponding to input of channel 5
  Channel_6 = TogglePinOutput(strobePin, 80)*ch6;   // 6.25khz sample
  DisplayLED(6, Channel_6);                         // Light sixth column corresponding to input of channel 6
  Channel_7 = TogglePinOutput(strobePin, 80)*ch7;   // 16kHz sample
  DisplayLED(7, Channel_7);                         // Light seventh column corresponding to input of channel 7



//////////////////////////////////////////////////////////////////////////////////////////////

//////////////////////////// For LOOP to clear display ///////////////////////////////////////

//////////////////////////////////////////////////////////////////////////////////////////////

  
// For loop clears LED display
  for (int j = 0; j < NumLEDS; j++)
    leds[j] = CRGB::C0;                             // Set LEDs to Black, which we also have set for no input 
  FastLED.show();
  
// Diagnostic printing of values read for all 7 channels 
  Serial.println(String("63: " + String(Channel_1) + " 160: " + String(Channel_2) + " 400: " + String(Channel_3) + " 1k: " + String(Channel_4) + " 2.5k: " + String(Channel_5) + " 6.25k: " + String(Channel_6) + " 16k: " + String(Channel_7)));
}

//////////////////////////////////////////////////////////////////////////////////////////////

////////////////////////////////////// Storbe Value //////////////////////////////////////////

//////////////////////////////////////////////////////////////////////////////////////////////

// Toggle for Strobe pin to get input frequencies
// Refer to Data Sheet if need further understanding  https://www.sparkfun.com/datasheets/Components/General/MSGEQ7.pdf
int TogglePinOutput(int tPin, int timeON) {   // Toggle pin, delay time in microseconds
  digitalWrite(tPin, LOW);                    // Toggle Pin set low, tPin = 0 
  delayMicroseconds(timeON);                  // Delayed need to return a value 
  int sensorValue = analogRead(sensorPin);    // Variable to store the value coming from the sensor
  digitalWrite(tPin, HIGH);                   // Toggle Pin set High, tPin = 1
  delayMicroseconds(timeON);                  // Delay needed to capture a value 
  return sensorValue;                         // Pass the value to find out to decide which channel  
}

void reset() {                                // Reset the mux on the equlizer chip
  digitalWrite(resetPin, HIGH);               // Reset Pin High =1 
  digitalWrite(resetPin, LOW);                // Reset Pin Low = 0
  delayMicroseconds(75);                      // Delay required for how long the reset pin goes high 
                                              // before reset pin goes low  
}

//////////////////////////////////////////////////////////////////////////////////////////////

////////////////////////////////////// Display LEDS //////////////////////////////////////////

//////////////////////////////////////////////////////////////////////////////////////////////

void DisplayLED(int Col, int PotValue)
{
  // Intialize how high the column goes up  
  int row1 = Col - 1 + (8 * 0);
  int row2 = Col - 1 + (8 * 1);
  int row3 = Col - 1 + (8 * 2);
  int row4 = Col - 1 + (8 * 3);
  int row5 = Col - 1 + (8 * 4);
  int row6 = Col - 1 + (8 * 5);
  int row7 = Col - 1 + (8 * 6);
  int row8 = Col - 1 + (8 * 7);


/* The statements below select which LEDS to light */
// 1st Column LEDs lights row 1-8
  if (PotValue > 15 && PotValue < 255)
  {
    switch (Col)
    {
      case 1:
        leds[row1] = CRGB::C1; 
        break;
      case 2:
        leds[row1] = CRGB::C2; 
        break;
      case 3:
        leds[row1] = CRGB::C3; 
        break;
      case 4:
        leds[row1] = CRGB::C4; 
        break;
      case 5:
        leds[row1] = CRGB::C5; 
        break;
      case 6:
        leds[row1] = CRGB::C6; 
        break;
      case 7:
        leds[row1] = CRGB::C7; 
        break;
      case 8:
        leds[row1] = CRGB::C8; 
        break;
    }
    FastLED.show();    
  }


// 2nd Column LEDs lights row 1-8
  if (PotValue > 255 && PotValue < 381)
  {
    switch (Col)
    {
      case 1:
        leds[row1] = CRGB::C1; 
        leds[row2] = CRGB::C1; 
        break;
      case 2:
        leds[row1] = CRGB::C2; 
        leds[row2] = CRGB::C2; 
        break;
      case 3:
        leds[row1] = CRGB::C3; 
        leds[row2] = CRGB::C3; 
        break;
      case 4:
        leds[row1] = CRGB::C4; 
        leds[row2] = CRGB::C4; 
        break;
      case 5:
        leds[row1] = CRGB::C5; 
        leds[row2] = CRGB::C5; 
        break;
      case 6:
        leds[row1] = CRGB::C6; 
        leds[row2] = CRGB::C6; 
        break;
      case 7:
        leds[row1] = CRGB::C7; 
        leds[row2] = CRGB::C7; 
        break;
      case 8:
        leds[row1] = CRGB::C8; 
        leds[row2] = CRGB::C8; 
        break;
    }
    FastLED.show();   
  }

// 3rd Column LEDs lights row 1-8
  else if (PotValue > 381 && PotValue < 508)
  {
    switch (Col)
    {
      case 1:
        leds[row1] = CRGB::C1; 
        leds[row2] = CRGB::C1; 
        leds[row3] = CRGB::C1; 
        break;
      case 2:
        leds[row1] = CRGB::C2; 
        leds[row2] = CRGB::C2; 
        leds[row3] = CRGB::C2;
        break;
      case 3:
        leds[row1] = CRGB::C3; 
        leds[row2] = CRGB::C3; 
        leds[row3] = CRGB::C3;
        break;
      case 4:
        leds[row1] = CRGB::C4; 
        leds[row2] = CRGB::C4; 
        leds[row3] = CRGB::C4;
        break;
      case 5:
        leds[row1] = CRGB::C5; 
        leds[row2] = CRGB::C5; 
        leds[row3] = CRGB::C5; 
        break;
      case 6:
        leds[row1] = CRGB::C6; 
        leds[row2] = CRGB::C6; 
        leds[row3] = CRGB::C6;
        break;
      case 7:
        leds[row1] = CRGB::C7; 
        leds[row2] = CRGB::C7; 
        leds[row3] = CRGB::C7;
        break;
      case 8:
        leds[row1] = CRGB::C8; 
        leds[row2] = CRGB::C8; 
        leds[row3] = CRGB::C8;
        break;
    }
    FastLED.show();    
  }

// 4th Column LEDs lights row 1-8
  else if (PotValue > 508 && PotValue < 635)
  {
    switch (Col)
    {
      case 1:
        leds[row1] = CRGB::C1;
        leds[row2] = CRGB::C1;
        leds[row3] = CRGB::C1;
        leds[row4] = CRGB::C1;
        break;
      case 2:
        leds[row1] = CRGB::C2;
        leds[row2] = CRGB::C2;
        leds[row3] = CRGB::C2;
        leds[row4] = CRGB::C2;
        break;
      case 3:
        leds[row1] = CRGB::C3;
        leds[row2] = CRGB::C3;
        leds[row3] = CRGB::C3;
        leds[row4] = CRGB::C3;
        break;
      case 4:
        leds[row1] = CRGB::C4;
        leds[row2] = CRGB::C4;
        leds[row3] = CRGB::C4;
        leds[row4] = CRGB::C4;
        break;
      case 5:
        leds[row1] = CRGB::C5;
        leds[row2] = CRGB::C5;
        leds[row3] = CRGB::C5;
        leds[row4] = CRGB::C5;
        break;
      case 6:
        leds[row1] = CRGB::C6;
        leds[row2] = CRGB::C6;
        leds[row3] = CRGB::C6;
        leds[row4] = CRGB::C6;
        break;
      case 7:
        leds[row1] = CRGB::C7;
        leds[row2] = CRGB::C7;
        leds[row3] = CRGB::C7;
        leds[row4] = CRGB::C7;
        break;
      case 8:
        leds[row1] = CRGB::C8;
        leds[row2] = CRGB::C8;
        leds[row3] = CRGB::C8;
        leds[row4] = CRGB::C8;
        break;
    }
    FastLED.show();    
  }


// 5th Column LEDs lights row 1-8
  else if (PotValue > 635 && PotValue < 762)
  {
    switch (Col)
    {
      case 1:
        leds[row1] = CRGB::C1;
        leds[row2] = CRGB::C1;
        leds[row3] = CRGB::C1;
        leds[row4] = CRGB::C1;
        leds[row5] = CRGB::C1;
        break;
      case 2:
        leds[row1] = CRGB::C2;
        leds[row2] = CRGB::C2;
        leds[row3] = CRGB::C2;
        leds[row4] = CRGB::C2;
        leds[row5] = CRGB::C2;
        break;
      case 3:
        leds[row1] = CRGB::C3;
        leds[row2] = CRGB::C3;
        leds[row3] = CRGB::C3;
        leds[row4] = CRGB::C3;
        leds[row5] = CRGB::C3;
        break;
      case 4:
        leds[row1] = CRGB::C4;
        leds[row2] = CRGB::C4;
        leds[row3] = CRGB::C4;
        leds[row4] = CRGB::C4;
        leds[row5] = CRGB::C4;
        break;
      case 5:
        leds[row1] = CRGB::C5;
        leds[row2] = CRGB::C5;
        leds[row3] = CRGB::C5;
        leds[row4] = CRGB::C5;
        leds[row5] = CRGB::C5;
        break;
      case 6:
        leds[row1] = CRGB::C6;
        leds[row2] = CRGB::C6;
        leds[row3] = CRGB::C6;
        leds[row4] = CRGB::C6;
        leds[row5] = CRGB::C6;
        break;
      case 7:
        leds[row1] = CRGB::C7;
        leds[row2] = CRGB::C7;
        leds[row3] = CRGB::C7;
        leds[row4] = CRGB::C7;
        leds[row5] = CRGB::C7;
        break;
      case 8:
        leds[row1] = CRGB::C8;
        leds[row2] = CRGB::C8;
        leds[row3] = CRGB::C8;
        leds[row4] = CRGB::C8;
        leds[row5] = CRGB::C8;
        break;
    }
    FastLED.show();    
  }

// 6th Column LEDs lights row 1-8
  else if (PotValue > 762 && PotValue < 889)
  {
    switch (Col)
    {
      case 1:
        leds[row1] = CRGB::C1;
        leds[row2] = CRGB::C1;
        leds[row3] = CRGB::C1;
        leds[row4] = CRGB::C1;
        leds[row5] = CRGB::C1;
        leds[row6] = CRGB::C1;
        break;
      case 2:
        leds[row1] = CRGB::C2;
        leds[row2] = CRGB::C2;
        leds[row3] = CRGB::C2;
        leds[row4] = CRGB::C2;
        leds[row5] = CRGB::C2;
        leds[row6] = CRGB::C2;
        break;
      case 3:
        leds[row1] = CRGB::C3;
        leds[row2] = CRGB::C3;
        leds[row3] = CRGB::C3;
        leds[row4] = CRGB::C3;
        leds[row5] = CRGB::C3;
        leds[row6] = CRGB::C3;
        break;
      case 4:
        leds[row1] = CRGB::C4;
        leds[row2] = CRGB::C4;
        leds[row3] = CRGB::C4;
        leds[row4] = CRGB::C4;
        leds[row5] = CRGB::C4;
        leds[row6] = CRGB::C4;
        break;
      case 5:
        leds[row1] = CRGB::C5;
        leds[row2] = CRGB::C5;
        leds[row3] = CRGB::C5;
        leds[row4] = CRGB::C5;
        leds[row5] = CRGB::C5;
        leds[row6] = CRGB::C5;
        break;
      case 6:
        leds[row1] = CRGB::C6;
        leds[row2] = CRGB::C6;
        leds[row3] = CRGB::C6;
        leds[row4] = CRGB::C6;
        leds[row5] = CRGB::C6;
        leds[row6] = CRGB::C6;
        break;
      case 7:
        leds[row1] = CRGB::C7;
        leds[row2] = CRGB::C7;
        leds[row3] = CRGB::C7;
        leds[row4] = CRGB::C7;
        leds[row5] = CRGB::C7;
        leds[row6] = CRGB::C7;
        break;
      case 8:
        leds[row1] = CRGB::C8;
        leds[row2] = CRGB::C8;
        leds[row3] = CRGB::C8;
        leds[row4] = CRGB::C8;
        leds[row5] = CRGB::C8;
        leds[row6] = CRGB::C8;
        break;
    }
    FastLED.show();    
  }

// 7th Column LEDs lights row 1-8
  else if (PotValue > 889 && PotValue < 1000)
  {
    switch (Col)
    {
      case 1:
        leds[row1] = CRGB::C1;
        leds[row2] = CRGB::C1;
        leds[row3] = CRGB::C1;
        leds[row4] = CRGB::C1;
        leds[row5] = CRGB::C1;
        leds[row6] = CRGB::C1;
        leds[row7] = CRGB::C1;
        break;
      case 2:
        leds[row1] = CRGB::C2;
        leds[row2] = CRGB::C2;
        leds[row3] = CRGB::C2;
        leds[row4] = CRGB::C2;
        leds[row5] = CRGB::C2;
        leds[row6] = CRGB::C2;
        leds[row7] = CRGB::C2;
        break;
      case 3:
        leds[row1] = CRGB::C3;
        leds[row2] = CRGB::C3;
        leds[row3] = CRGB::C3;
        leds[row4] = CRGB::C3;
        leds[row5] = CRGB::C3;
        leds[row6] = CRGB::C3;
        leds[row7] = CRGB::C3;
        break;
      case 4:
        leds[row1] = CRGB::C4;
        leds[row2] = CRGB::C4;
        leds[row3] = CRGB::C4;
        leds[row4] = CRGB::C4;
        leds[row5] = CRGB::C4;
        leds[row6] = CRGB::C4;
        leds[row7] = CRGB::C4;
        break;
      case 5:
        leds[row1] = CRGB::C5;
        leds[row2] = CRGB::C5;
        leds[row3] = CRGB::C5;
        leds[row4] = CRGB::C5;
        leds[row5] = CRGB::C5;
        leds[row6] = CRGB::C5;
        leds[row7] = CRGB::C5;
        break;
      case 6:
        leds[row1] = CRGB::C6;
        leds[row2] = CRGB::C6;
        leds[row3] = CRGB::C6;
        leds[row4] = CRGB::C6;
        leds[row5] = CRGB::C6;
        leds[row6] = CRGB::C6;
        leds[row7] = CRGB::C6;
        break;
      case 7:
        leds[row1] = CRGB::C7;
        leds[row2] = CRGB::C7;
        leds[row3] = CRGB::C7;
        leds[row4] = CRGB::C7;
        leds[row5] = CRGB::C7;
        leds[row6] = CRGB::C7;
        leds[row7] = CRGB::C7;
        break;
      case 8:
        leds[row1] = CRGB::C8;
        leds[row2] = CRGB::C8;
        leds[row3] = CRGB::C8;
        leds[row4] = CRGB::C8;
        leds[row5] = CRGB::C8;
        leds[row6] = CRGB::C8;
        leds[row7] = CRGB::C8;
        break;
    }
    FastLED.show();    
  }

// 8th Column LEDs lights row 1-8
  else if (PotValue > 1000 && PotValue < 20000)
  {
    switch (Col)
    {
      case 1:
        leds[row1] = CRGB::C1;
        leds[row2] = CRGB::C1;
        leds[row3] = CRGB::C1;
        leds[row4] = CRGB::C1;
        leds[row5] = CRGB::C1;
        leds[row6] = CRGB::C1;
        leds[row7] = CRGB::C1;
        leds[row8] = CRGB::C1;
        break;
      case 2:
        leds[row1] = CRGB::C2;
        leds[row2] = CRGB::C2;
        leds[row3] = CRGB::C2;
        leds[row4] = CRGB::C2;
        leds[row5] = CRGB::C2;
        leds[row6] = CRGB::C2;
        leds[row7] = CRGB::C2;
        leds[row8] = CRGB::C2;
        break;
      case 3:
        leds[row1] = CRGB::C3;
        leds[row2] = CRGB::C3;
        leds[row3] = CRGB::C3;
        leds[row4] = CRGB::C3;
        leds[row5] = CRGB::C3;
        leds[row6] = CRGB::C3;
        leds[row7] = CRGB::C3;
        leds[row8] = CRGB::C3;
        break;
      case 4:
        leds[row1] = CRGB::C4;
        leds[row2] = CRGB::C4;
        leds[row3] = CRGB::C4;
        leds[row4] = CRGB::C4;
        leds[row5] = CRGB::C4;
        leds[row6] = CRGB::C4;
        leds[row7] = CRGB::C4;
        leds[row8] = CRGB::C4;
        break;
      case 5:
        leds[row1] = CRGB::C5;
        leds[row2] = CRGB::C5;
        leds[row3] = CRGB::C5;
        leds[row4] = CRGB::C5;
        leds[row5] = CRGB::C5;
        leds[row6] = CRGB::C5;
        leds[row7] = CRGB::C5;
        leds[row8] = CRGB::C5;
        break;
      case 6:
        leds[row1] = CRGB::C6;
        leds[row2] = CRGB::C6;
        leds[row3] = CRGB::C6;
        leds[row4] = CRGB::C6;
        leds[row5] = CRGB::C6;
        leds[row6] = CRGB::C6;
        leds[row7] = CRGB::C6;
        leds[row8] = CRGB::C6;
        break;
      case 7:
        leds[row1] = CRGB::C7;
        leds[row2] = CRGB::C7;
        leds[row3] = CRGB::C7;
        leds[row4] = CRGB::C7;
        leds[row5] = CRGB::C7;
        leds[row6] = CRGB::C7;
        leds[row7] = CRGB::C7;
        leds[row8] = CRGB::C7;
        break;
      case 8:
        leds[row1] = CRGB::C8;
        leds[row2] = CRGB::C8;
        leds[row3] = CRGB::C8;
        leds[row4] = CRGB::C8;
        leds[row5] = CRGB::C8;
        leds[row6] = CRGB::C8;
        leds[row7] = CRGB::C8;
        leds[row8] = CRGB::C8;
        break;
    }
// Actually pushes to the LEDs
    FastLED.show();    
  }
}

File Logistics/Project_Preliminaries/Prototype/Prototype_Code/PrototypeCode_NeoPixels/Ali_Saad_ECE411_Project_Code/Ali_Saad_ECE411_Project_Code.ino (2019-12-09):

//This program will route sound via a mic and send it to NEOPIXELS

#include <FastLED.h>

// Pin Assignments
#define DataPin 7   // Pin that communicates to LED output strip 
#define RESETPIN 5  // Pin for reset button
#define STROBEPIN 4 // Pin connecting to strobe of the filter chip 
#define CHIP A2     // Connect to the 7 BandPass filter chip 

// Potentiometer for each row
#define pot1Pin 0 // Potentiometer for 1st row of LEDs
#define pot2Pin 1 // Potentiometer for 2nd row of LEDs
#define pot3Pin 2 // Potentiometer for 3rd row of LEDs
#define pot4Pin 3 // Potentiometer for 4th row of LEDs
#define pot5Pin 4 // Potentiometer for 5th row of LEDs
#define pot6Pin 5 // Potentiometer for 6th row of LEDs
#define pot7Pin 6 // Potentiometer for 7th row of LEDs
#define pot8Pin 7 // Potentiometer for 8th row of LEDs

// Delay Value
#define STRD 0.072    // Delay for strobe cycle
#define VALD 0.036    // Delay for a valid data, waiting data ready
#define REMAIN 0.036  // Delay for the remaining time

// Color Assignments
#define C0 Black  // no input
#define C1 Red    // 1st row of LEDs
#define C2 Green  // 2nd row of LEDs
#define C3 Blue   // 3rd row of LEDs
#define C4 Yellow // 4th row of LEDs
#define C5 Purple // 5th row of LEDs
#define C6 White  // 6th row of LEDs
#define C7 Aqua   // 7th row of LEDs
#define C8 Orange // 8th row of LEDs

// Array Assignments
#define NumLEDS 64 // 8 x 8 NeoPixel LED Array = 64 total LEDs
CRGB leds[NumLEDS]; 

// Setup for the pixels
void setup() 
{ 
    // Brought in from the FastLED Library
    FastLED.addLeds<NEOPIXEL, DataPin>(leds, NumLEDS);
    Serial.begin(57600); // start a serial monitor
    
    /*
    Not needed per Marks comments. No reference ground is needed
    analogReference(INTERNAL); // Sets the AREF to 2.5 for the reference for the filter chip
    analogWrite(IO11,127); // (MAYBE?) Sets the clock signal to the IO11 Pin at 50% duty cycle
    */

    // Sets the Reset and Strobe pins as ooutputs
    digitalWrite(RESETPIN, OUTPUT); 
    digitalWrite(STROBEPIN, OUTPUT);

    // Sending the strobe and reset signals to initialize the filter
    digitalWrite(RESETPIN, HIGH); //reset = 1
    int strobe = 1;
    digitalWrite(STROBEPIN, strobe); //strobe = 1
    strobe = strobeChip(strobe); // delay then strobe is LOW
    strobe = strobeChip(strobe); // delay then Strobe is HIGH
    digitalWrite(RESETPIN, LOW); // Reset = 0
}

// This will loop for all of time
void loop() 
{
    /*
       THIS IS OLD CODE
    // Reading in from the 8 band pass filters
    int pot1 = analogRead(pot1Pin);
    int pot2 = analogRead(pot2Pin);
    int pot3 = analogRead(pot3Pin);
    int pot4 = analogRead(pot4Pin);
    int pot5 = analogRead(pot5Pin);
    int pot6 = analogRead(pot6Pin);
    int pot7 = analogRead(pot7Pin);
    int pot8 = analogRead(pot8Pin);
*/

    //Serial.println(pot8);
     

    /*   Serial.print(" Value 1: ");Serial.print(pot1);Serial.print(" Value 2: ");Serial.print(pot2);Serial.print(" Value 3: ");Serial.print(pot3);Serial.print(" Value 4: ");Serial.print(pot4);
         Serial.print(" Value 5: ");Serial.print(pot5);Serial.print(" Value 6: ");Serial.print(pot6);Serial.print(" Value 7: ");Serial.print(pot7);Serial.print(" Value 8: ");Serial.println(pot8);
     */
    for (int i = 1; i < 8; i++)
    {
       int strobe = HIGH;
       // Serial.println(strobe);
       strobe = strobeChip(strobe); // delay then Strobe is HIGH
       int pot1, pot2, pot3, pot4, pot5, pot6, pot7;
       // Monitor the value of all potentiometers
       char printer[99];  
      sprintf(printer, "Value 1: %d  Value2: %d  Value3: %d  Value4: %d  Value5: %d  Value6: %d  Value7: %d", pot1, pot2, pot3, pot4, pot5, pot6, pot7);
      Serial.println(printer);
            
        // Sets the number of LEDS for the volume level
        switch (i)
        {
            case(1): // 63 Hz
                pot1 = getSample();
                setLEDcolor(1, pot1);
            case(2): // 160 Hz
                pot2 = getSample();
                setLEDcolor(2, pot2);
            case(3): // 400 Hz
                pot3 = getSample();
                setLEDcolor(3, pot3);
            case(4): // 1 kHz
                pot4 = getSample();
                setLEDcolor(4, pot4);
            case(5): // 2.5 kHz
                pot5 = getSample();
                setLEDcolor(5, pot5);
            case(6): //6.25 kHz
                pot6 = getSample();
                setLEDcolor(6, pot6);
            case(7): // 16 kHz
                pot7 = getSample();
                setLEDcolor(7, pot7);
            /*
            // No 8th row like this. Need to think of another way to use it
            
            case(8):
                pot8 = getSample();
                setLEDcolor(8, pot8);
            */    
        }
        
                // Turns all LEDS Off if there is "no signal"
                for (int j = 0; j < NumLEDS; j++)
                    leds[j] = CRGB::C0;
                FastLED.show();
                
    }
}

int getSample()
{
    // Will comunicate (notsure how) with the filter chip to get the value of each filter
    /* Data comes in the following order
        63 Hz
        160 Hz
        400 Hz
        1.0 KHz
        2.5 KHz
        6.25 KHz
        16 KHz
        REPEATS
        63 Hz
        160 Hz
        400 Hz
    */
    
    delay(VALD); // Delay for valid data    
    return analogRead(CHIP);
}

int strobeChip(int old)
{
    // Will strobe the filter chip
    /* 
    Reset goes high for min of 100us (delay(0.1))
    After a reset: Valid data and output settling time = 208us (delay(0.208))
    Output Settling Time is 36us min (delay(0.036))
    Strobe religiously every 72us (delay(0.072))
    */
    delay(STRD);
    return !old;
}


void nextFilter()
{
    // Will select the next filter on the filter chip
}
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

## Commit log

2019-10-10 Create CAD
2019-10-23 Schematics
    Added the schematics and gerber files
2019-10-24 Schematic revision
2019-10-25 Prototype Code
2019-10-26 Update Prototype_Code.ino
    Proof of concept code. This code checks the DC voltage that gets through each bandpass filter. We used 3 bandpass filters with center frequencies of 60 Hz, 400 Hz, and 3.3 kHz. The output of each fil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
2019-10-27 Schematic Revised along with PCB Design
    Final Design changes made
2019-10-27 Filter design
    Very ruff filter designs
2019-10-30 Created ProjectCode.ino for sample of Neopixels LEDS
2019-10-30 Update Schematic and added datasheet for atmega32U4
2019-10-30 Moved NeoPixels test to Prototype Code folder
2019-10-31 Update Schematic
    [Filters.xlsx]
2019-11-07 Layouts Added
    Layouts of the Processor PCB
2019-11-07 Reorganized folders and added PCB layouts
2019-11-08 BOM for Processor board
    [BOM_ATMega32U4 Arduino Micro Clone_Processor.csv]
2019-11-14 1 pot to 1 led. value changes brightness independently
2019-11-14 Block diagram and bill of materials
    Updated block diagram and added bill of materials
    [BOM ECE411.csv]
2019-11-14 BOM UPDATE
    [BOM ECE411.csv, BOM ECE411.xlsx]
2019-11-14 Gerber Ver1.1
    Fixed flipped transistors Q1 and Q2 ,Added width to power trace, fixed silkscreen readability
2019-11-21 add a switch and serial output
2019-11-21 Ver1.1 Upload
    Added Ver 1.1 Schematic , gerber, and layout.
2019-11-29 pushing my progress on the switch for the filter
2019-11-30 Reorganized Folders/Files
    [BOM_1stBoard_LCSC.xlsx, BOM_2ndBoard_LCSC.xlsx, Filters.xlsx]
2019-12-03 adding my progress on the filter chip intergration
2019-12-04 Revised version of boards
    Change the folders and added missing documents for versions 1.0 to 1.3 of board schematic and layout files
    [ATMEGA32U4+Micro+Ver1.0.schdoc, ATMEGA32U4+Micro+Ver1.1.schdoc, ATMEGA32U4+Micro+Ver1.2.schdoc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]
2019-12-11 Fixed BOM Display Error
    [BOM.xlsx]
2019-12-11 Deleted BOM containing error
    [BOM_ECE411_20191123153145.csv]
2019-12-11 Changed BOM Link
2019-12-11 Fixed Link to Arduino Source Code
